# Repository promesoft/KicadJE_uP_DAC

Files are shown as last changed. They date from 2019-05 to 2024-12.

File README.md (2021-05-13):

# KicadJE_uP_DAC
Eurorack DAC output

# Purpose
Use for DDS/DCO - LFO - ADSR - Effects unit

# Status - Preliminary mounted
## Initial 
| Stage  | Detail | Status |
| --- | --- | --- |
| create material  | sch/pcb | OK  |
| | gerber | OK |
| production  | | ok |
|  | produced | ok |
|  | delivered | ok |
## Preliminary validation
| Test  | Detail | Status |
| --- | --- | --- |
| Initial Inspection | | OK |
| Initial Technical Test | ATMega32A DAC | ADC not working due to GND conn to Aref |
| Initial Technical Test | STM32 DAC |  |
| Initial Technical Test | VCO555 | Initial version not oscillating - add 270R across C603 to make it work |
|  |  | TL074 warm |
| Initial Product Test | ATMega32A DAC |  |
| Initial Product Test | STM32 DAC |  |
| Initial Product Test | VCO555 |  |
| Power Draw | ATMega32A DAC | Proto - no DAC: 2mA -12V, 2mA +12V, 30mA +5V |
| Power Draw | STM32 DAC |  |
| Power Draw | VCO555 |  |

## Secondary validation
| Test  | Detail | Status |
| --- | --- |--- |
| Product Test |  | |
| Product Test |  |  |
| Quality | | |
| Quality | | |
| Long Term Product Test |  |  |
| Power Draw | ATMega32A DAC |  |
| Power Draw | STM32 DAC |  |
| Power Draw | VCO555 |  |

## Errata
### Errata - VCO 555
1 - No oscillation fixed by replacing C603 w resistor (tested w 270R)
### Errata - ADSR Mega32
1 - ADC not working due to GND conn to Aref
### Errata - STM32 DAC

## Issues and Notes
### VCO 555

### ADSR Mega32
ADC not fast enough for audio

### STM32 DAC

# Pictures
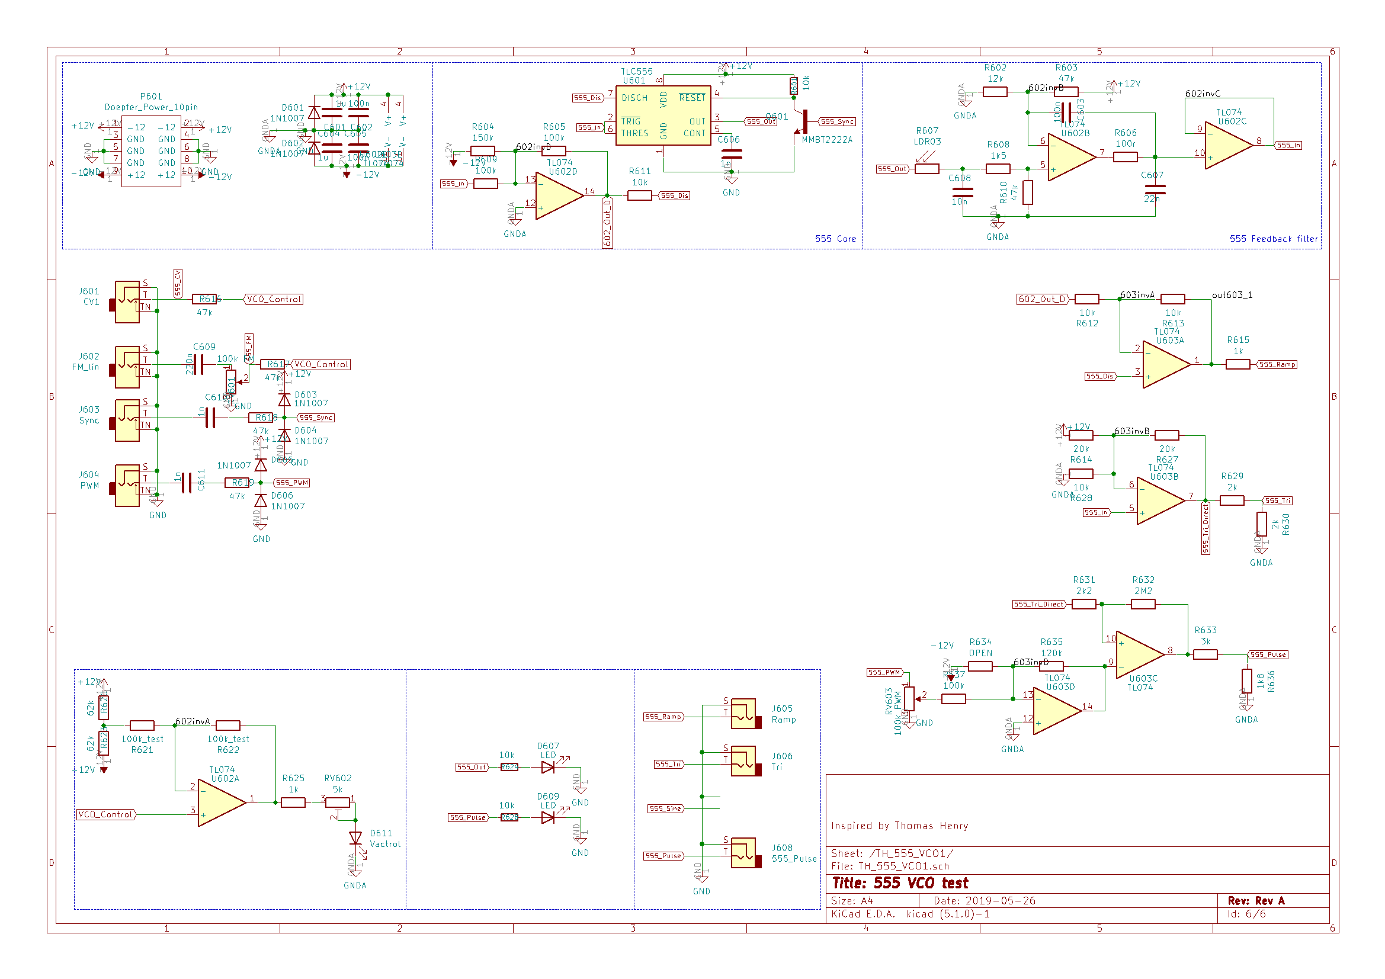
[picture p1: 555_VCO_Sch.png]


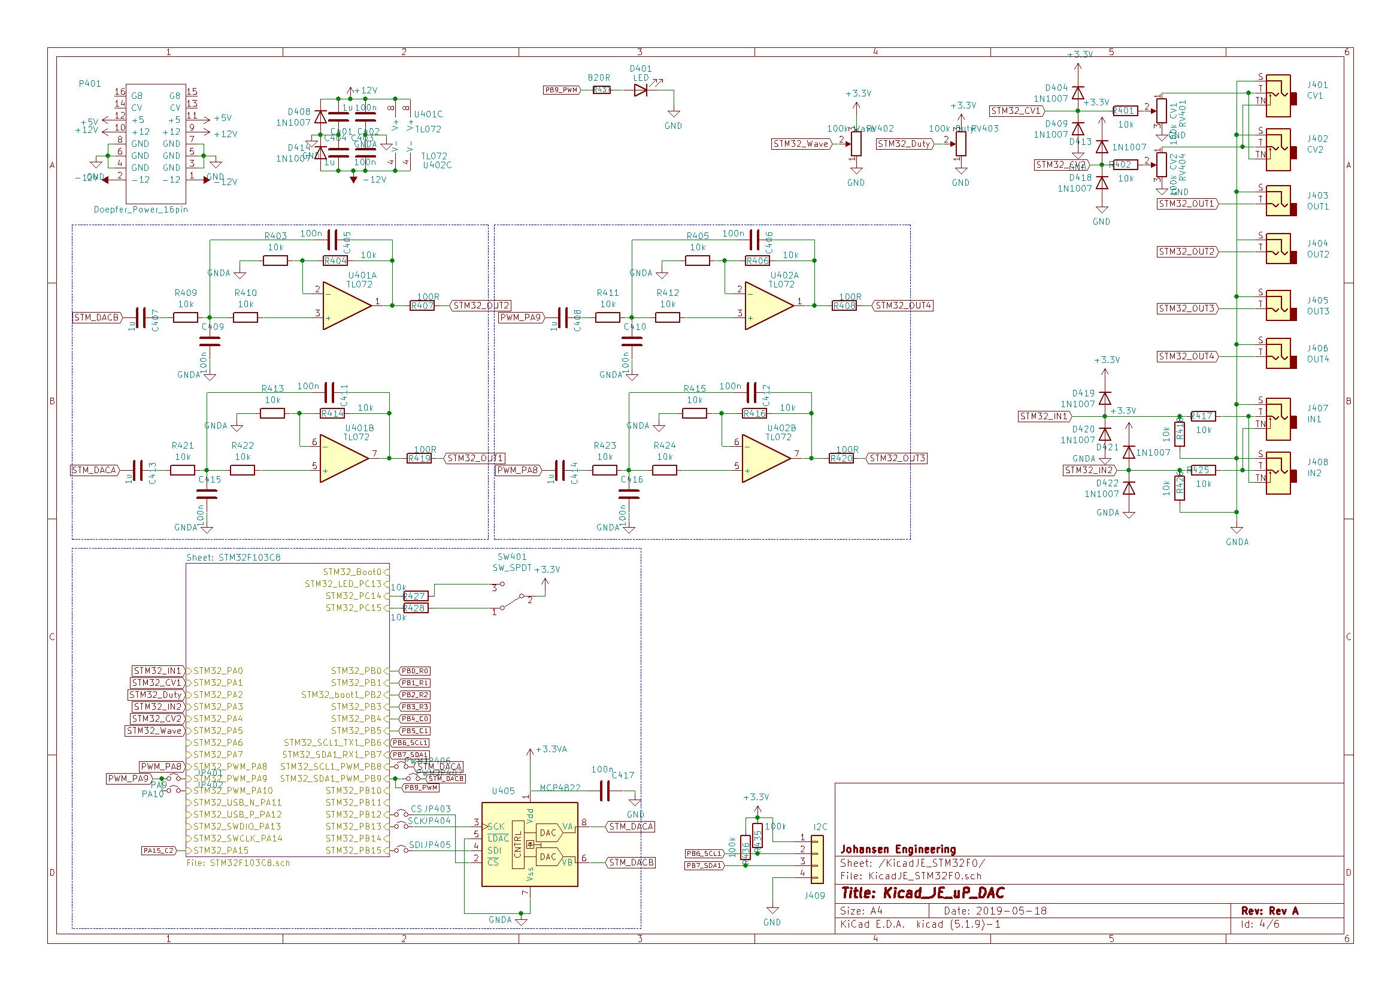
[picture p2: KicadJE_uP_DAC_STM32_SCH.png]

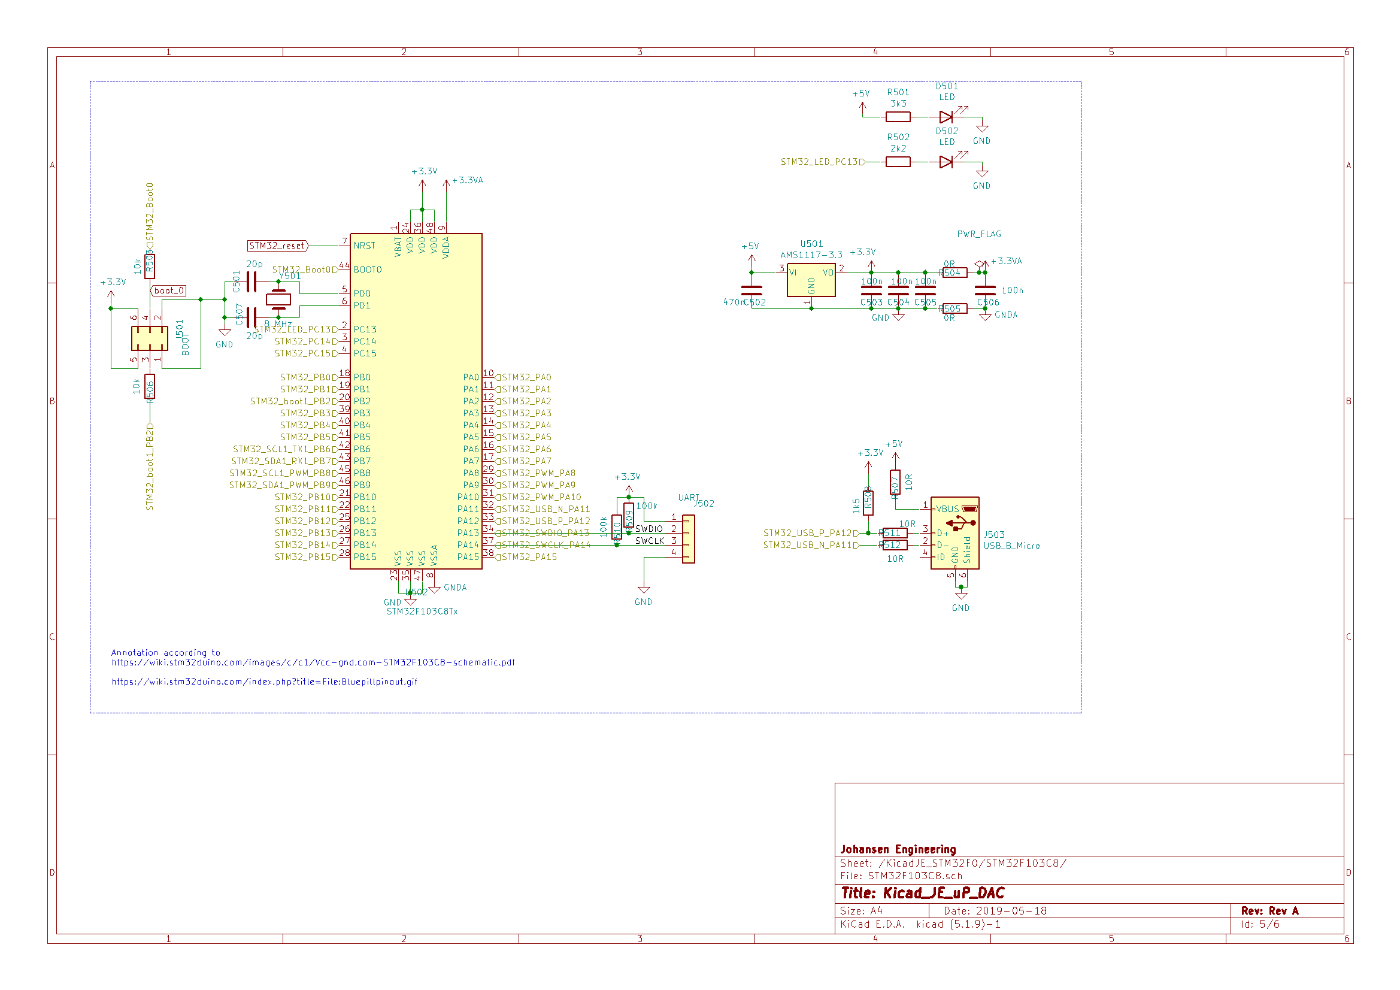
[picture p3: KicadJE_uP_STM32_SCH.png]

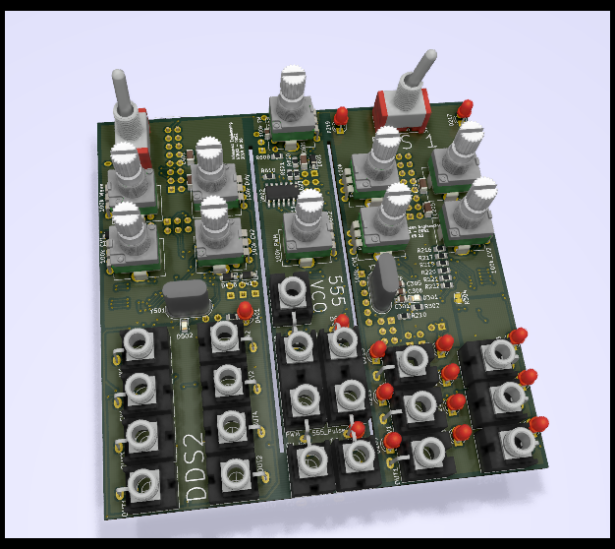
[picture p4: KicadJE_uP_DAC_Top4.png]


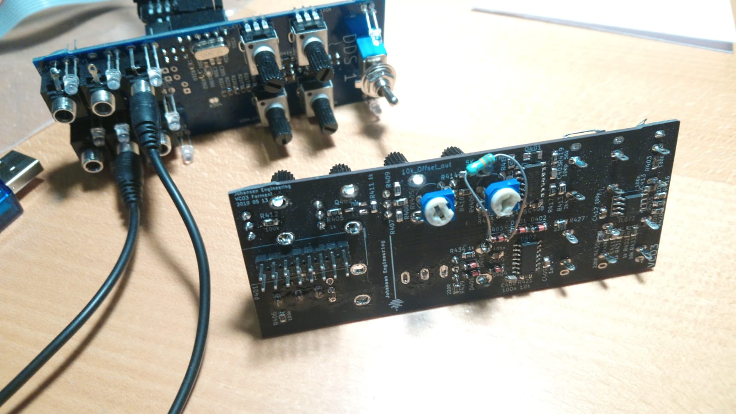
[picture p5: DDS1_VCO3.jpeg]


# Other components
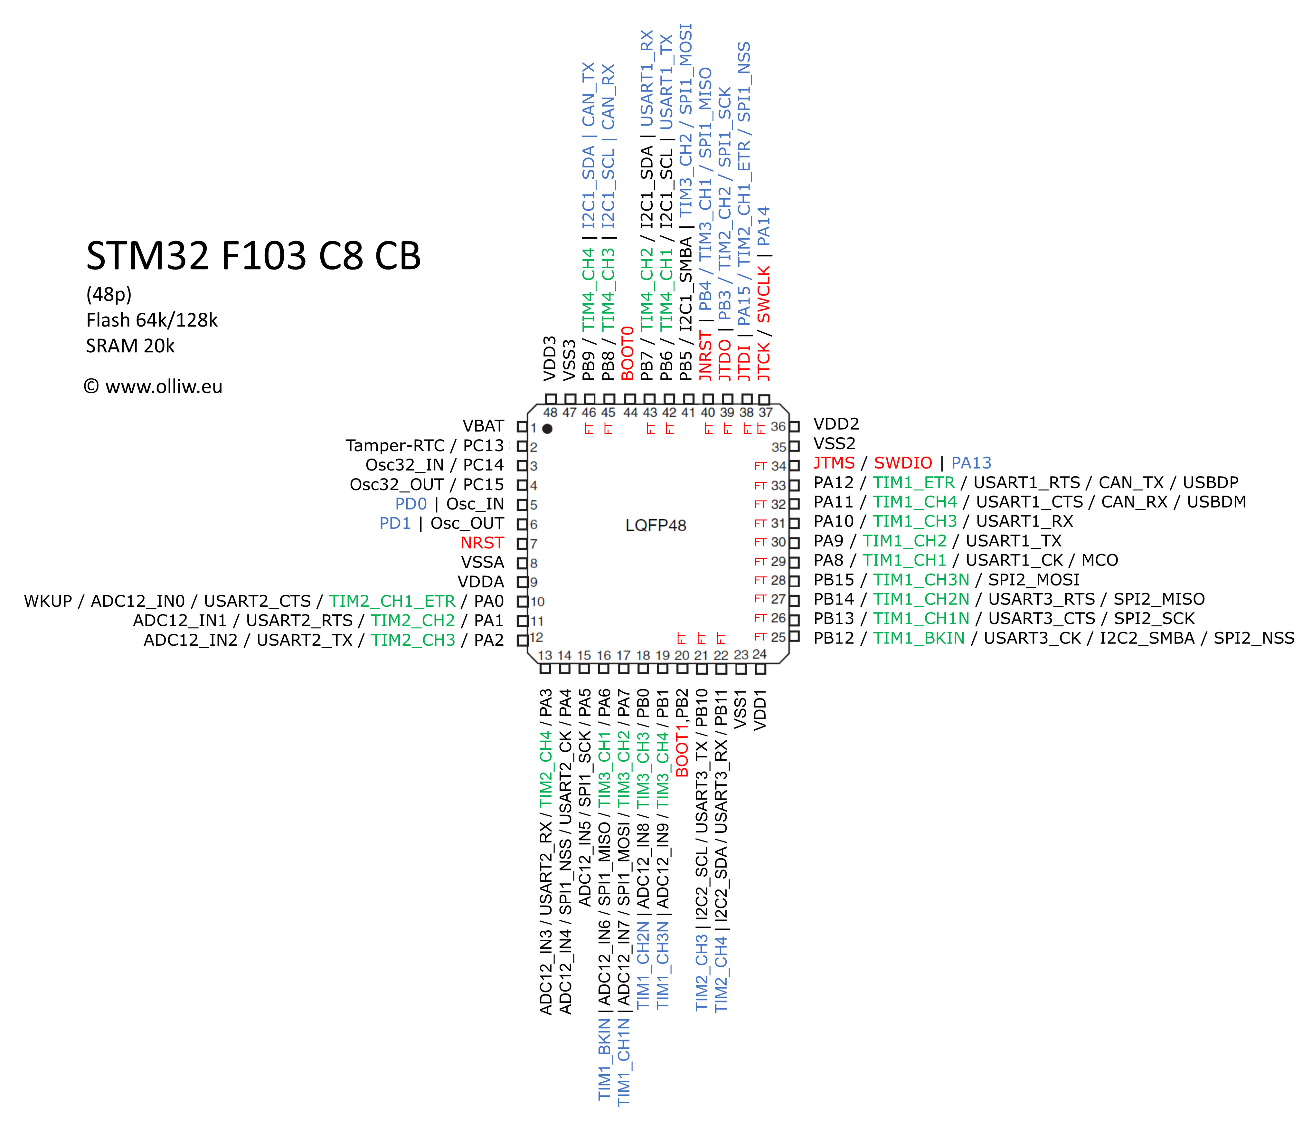
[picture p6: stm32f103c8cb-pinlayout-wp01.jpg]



# Inspiration
## ATMega 32A
https://github.com/MCUdude/MightyCore
## STM32

## Simple 555 VCO

### Own Projects
https://github.com/promesoft/KicadFormantVCO

https://github.com/promesoft/KicadJE_LFO_1

### Intro about 555
https://www.electronics-tutorials.ws/waveforms/555_oscillator.html

### Thomas Henry 555 VCO

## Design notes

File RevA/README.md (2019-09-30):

# KicadJE_uP_DAC
Eurorack DAC output

# Purpose
Use for DDS/DCO - LFO - ADSR - Effects unit

# Status - Preliminary SCH/PCB In the mail
## Initial 
| Stage  | Detail | Status |
| --- | --- | --- |
| create material  | sch/pcb | OK  |
| | gerber | OK |
| production  | | Ordered |
|  | produced | Pending |
|  | delivered | in the mail |
## Preliminary validation
| Test  | Detail | Status |
| --- | --- | --- |
| Initial Inspection | |  |
| Initial Technical Test | ATMega32A DAC |  |
| Initial Technical Test | STM32 DAC |  |
| Initial Technical Test | VCO555 |  |
| Initial Product Test | ATMega32A DAC |  |
| Initial Product Test | STM32 DAC |  |
| Initial Product Test | VCO555 |  |

## Secondary validation
| Test  | Detail | Status |
| --- | --- |--- |
| Product Test |  | |
| Product Test |  |  |
| Quality | | |
| Quality | | |
| Long Term Product Test |  |  |
| Power Draw |  | 

## Errata
### Errata -

## Issues and Notes
### 

# Pictures



# Other components



# Inspiration
## ATMega 32A
https://github.com/MCUdude/MightyCore
## STM32

## Simple 555 VCO

### Own Projects
https://github.com/promesoft/KicadFormantVCO

https://github.com/promesoft/KicadJE_LFO_1

### Intro about 555
https://www.electronics-tutorials.ws/waveforms/555_oscillator.html

### Thomas Henry 555 VCO
Nice comprehensive VCO

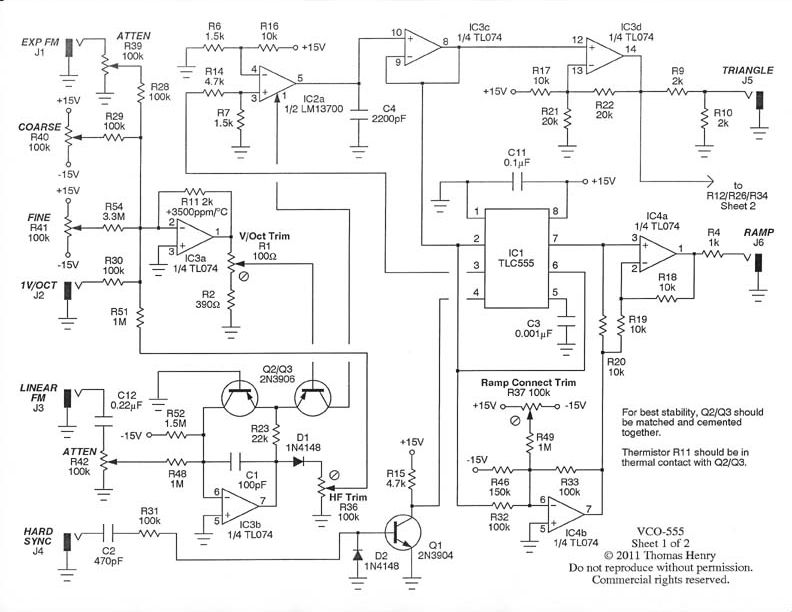
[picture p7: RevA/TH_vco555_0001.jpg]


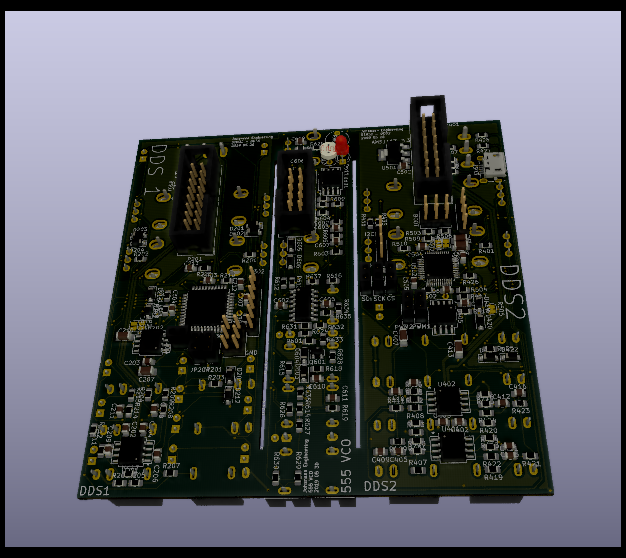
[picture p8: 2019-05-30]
RevA/KicadJE_uP_DAC_Bottom1.png

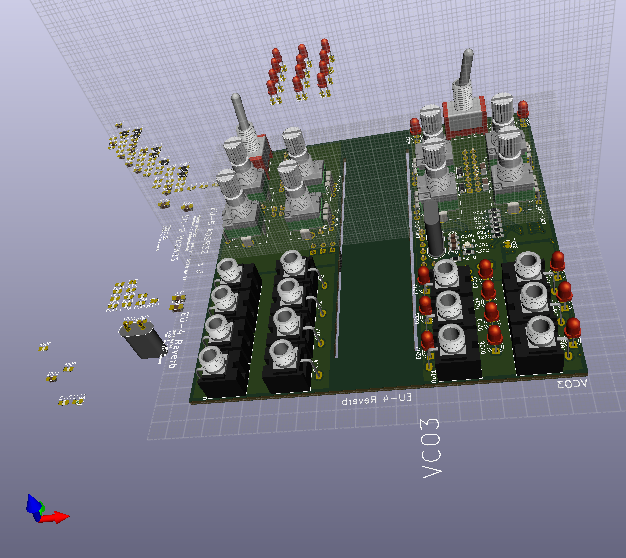
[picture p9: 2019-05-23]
RevA/KicadJE_uP_DAC_Top1.png

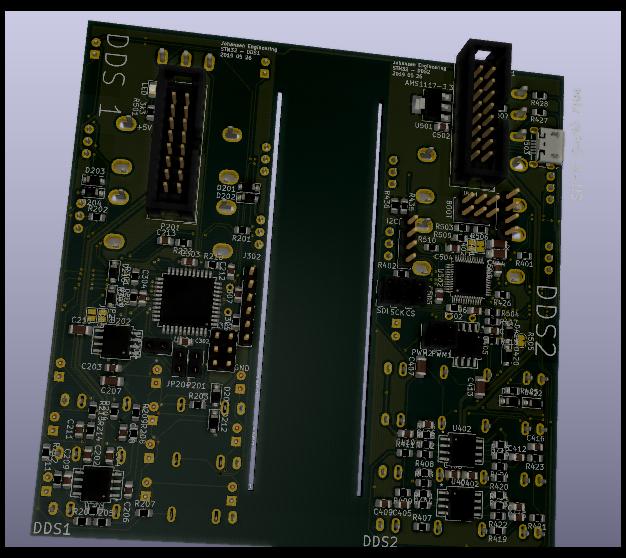
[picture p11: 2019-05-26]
RevA/KicadJE_uP_DAC_back2.jpg

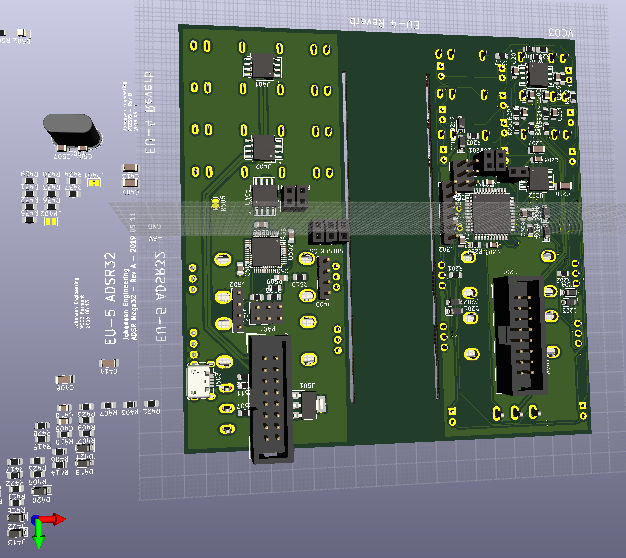
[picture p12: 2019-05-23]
RevA/KicadJE_uP_DAC.png

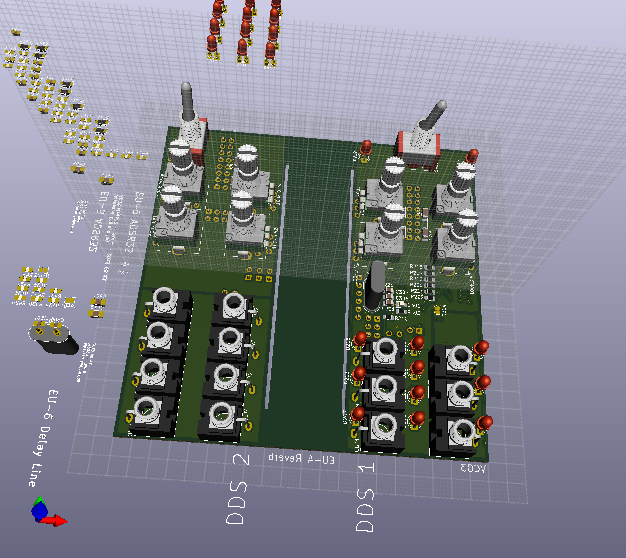
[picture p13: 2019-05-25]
RevA/KicadJE_uP_DAC_Top2.png

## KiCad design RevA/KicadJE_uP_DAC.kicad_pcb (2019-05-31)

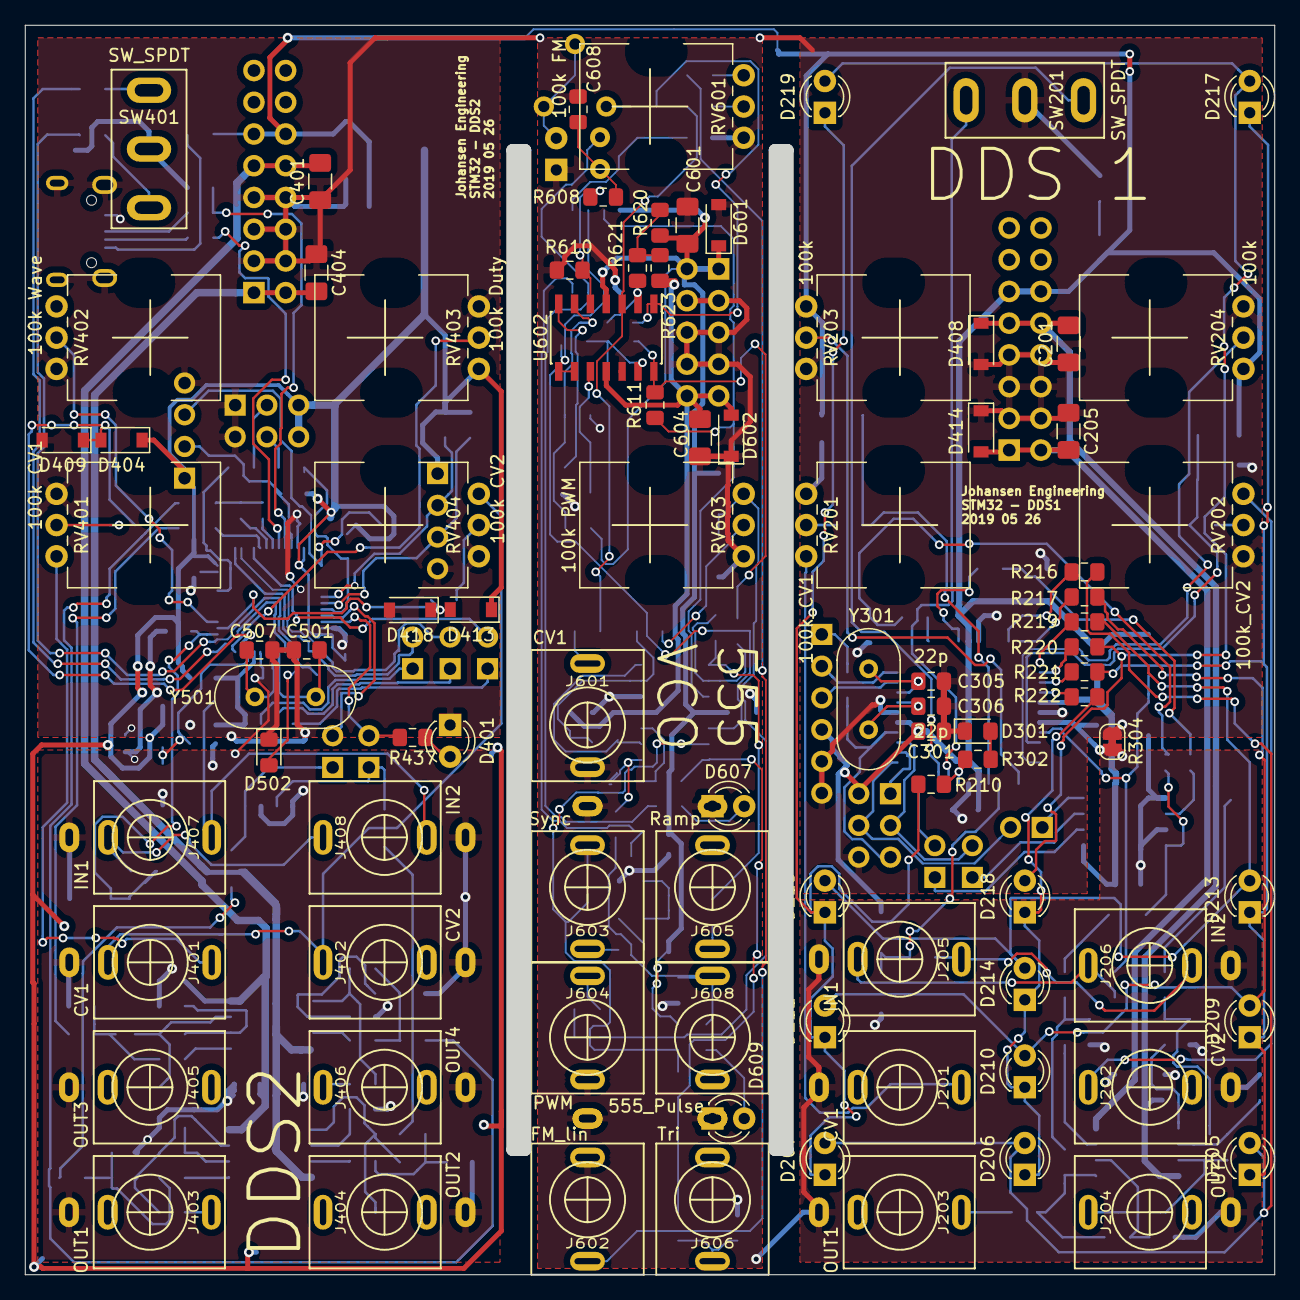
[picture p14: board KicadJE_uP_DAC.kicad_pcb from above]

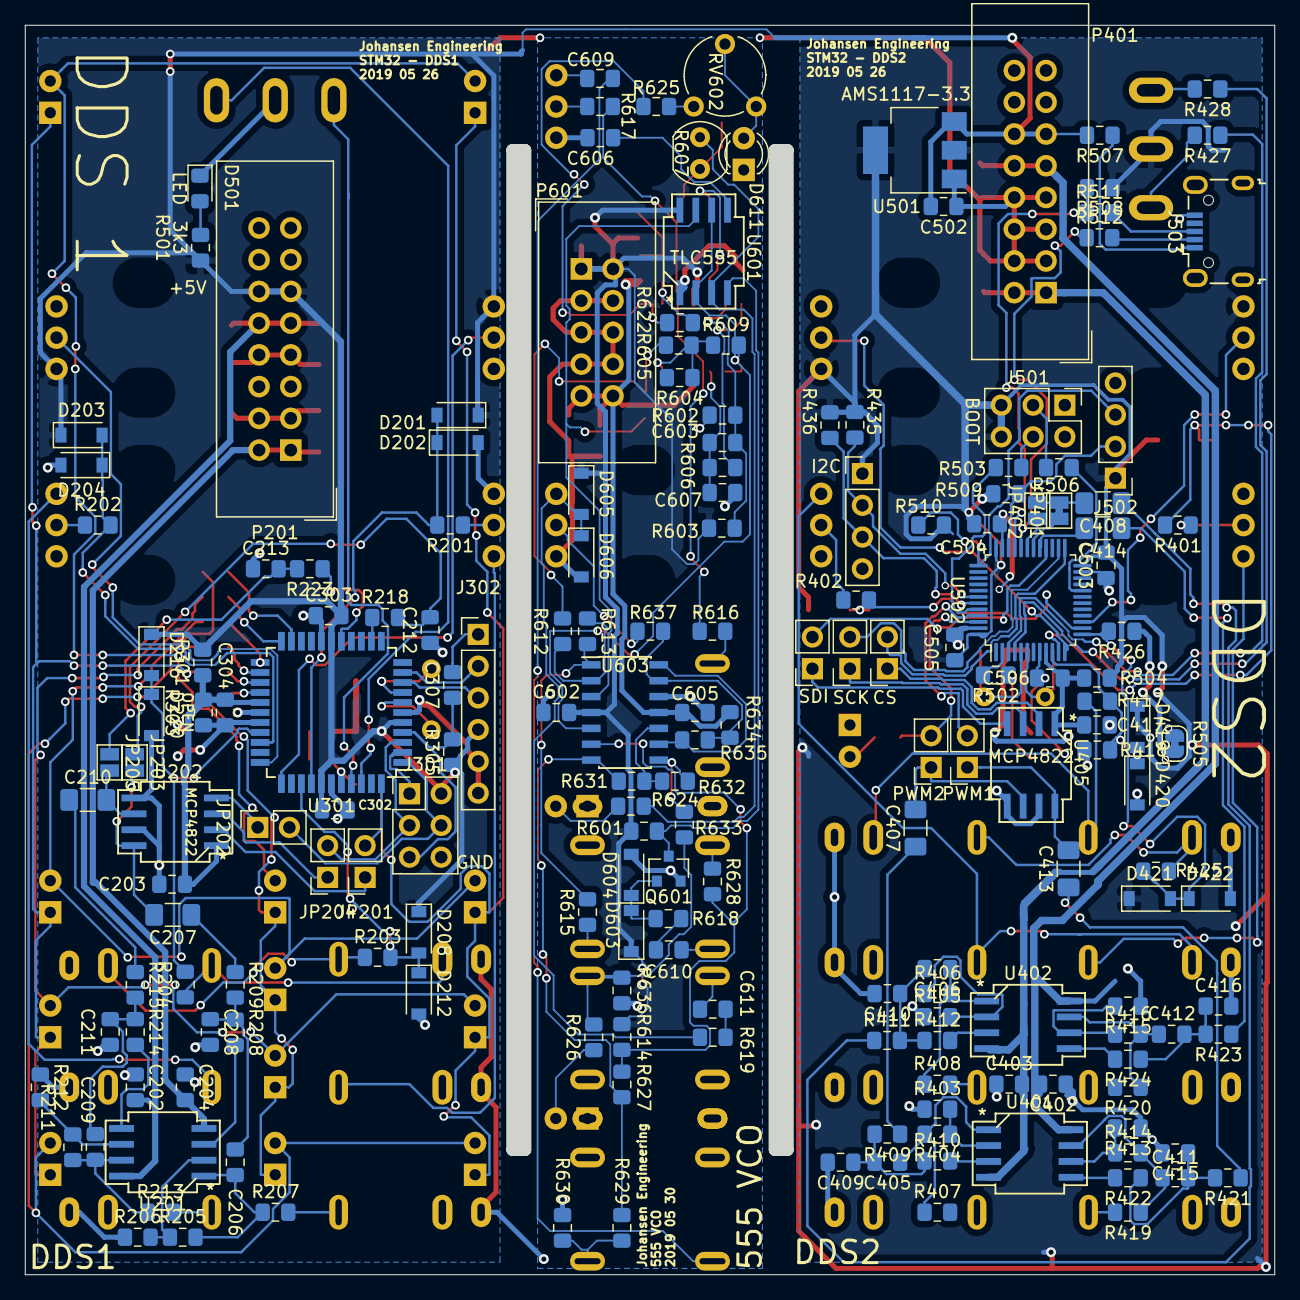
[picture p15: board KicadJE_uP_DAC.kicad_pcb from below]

Board: 2 copper layers, 100.0 x 100.0 mm, 275 parts (186 on the bottom side), 182 nets.

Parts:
C201, C205, C207, C210, C401, C404, C407, C408, C413, C414, C601, C604: 1u; C_1206_3216Metric_Pad1.42x1.75mm_HandSolder
C202, C203, C204, C206, C208, C209, C211, C212, C213, C301, C302, C303, C304, C307, C402, C403, C405, C406, C409, C410, C411, C412, C415, C416, C417, C503, C504, C505, C506, C602, C603, C605: 100n; C_0805_2012Metric_Pad1.15x1.40mm_HandSolder
C305, C306: 22p; C_0805_2012Metric_Pad1.15x1.40mm_HandSolder
C501, C507: 20p; C_0805_2012Metric_Pad1.15x1.40mm_HandSolder
C502: 470n; C_0805_2012Metric_Pad1.15x1.40mm_HandSolder
C606, C610, C611: 1n; C_0805_2012Metric_Pad1.15x1.40mm_HandSolder
C607: 22n; C_0805_2012Metric_Pad1.15x1.40mm_HandSolder
C608: 10n; C_0805_2012Metric_Pad1.15x1.40mm_HandSolder
C609: 220n; C_0805_2012Metric_Pad1.15x1.40mm_HandSolder
D201, D202, D203, D204, D208, D212, D216, D220, D404, D408, D409, D413, D414, D418, D419, D420, D421, D422, D601, D602, D603, D604, D605, D606: 1N1007; D_SOD-123
D205, D206, D207, D209, D210, D211, D213, D214, D215, D217, D218, D219, D401, D607, D609: LED; LED_D3.0mm
D301, D501, D502: LED; LED_0805_2012Metric_Pad1.15x1.40mm_HandSolder
D611: Vactrol; LED_D3.0mm
J201, J401, J601: CV1; PJ301SM
J202, J402: CV2; PJ301SM
J203, J403: OUT1; PJ301SM
J204, J404: OUT2; PJ301SM
J205, J407: IN1; PJ301SM
J206, J408: IN2; PJ301SM
J301: AVR-ISP-6; PinHeader_2x03_P2.54mm_Vertical
J302: UART; PinHeader_1x06_P2.54mm_Vertical
J405: OUT3; PJ301SM
J406: OUT4; PJ301SM
J409: I2C; PinHeader_1x04_P2.54mm_Vertical
J501: BOOT; PinHeader_2x03_P2.54mm_Vertical
J502: UART; PinHeader_1x04_P2.54mm_Vertical
J503: USB_B_Micro; USB_Micro-B_Wuerth_629105150521
J602: FM_lin; PJ301SM
J603: Sync; PJ301SM
J604: PWM; PJ301SM
J605: Ramp; PJ301SM
J606: Tri; PJ301SM
J608: 555_Pulse; PJ301SM
JP201: SS; PinSocket_1x02_P2.54mm_Vertical
JP202: MOSI; PinSocket_1x02_P2.54mm_Vertical
JP203: PWM1; SolderJumper-2_P1.3mm_Open_Pad1.0x1.5mm
JP204, JP404: SCK; PinSocket_1x02_P2.54mm_Vertical
JP205: PWM2; SolderJumper-2_P1.3mm_Open_Pad1.0x1.5mm
JP401: PA9; SolderJumper-2_P1.3mm_Bridged_Pad1.0x1.5mm
JP402: PA10; SolderJumper-2_P1.3mm_Open_Pad1.0x1.5mm
JP403: CS; PinSocket_1x02_P2.54mm_Vertical
JP405: SDI; PinSocket_1x02_P2.54mm_Vertical
JP406: PWM1; PinSocket_1x02_P2.54mm_Vertical
JP407: PWM2; PinSocket_1x02_P2.54mm_Vertical
P201, P401: Doepfer_Power_16pin; IDC-Header_2x08_Pitch2.54mm_Straight
P601: Doepfer_Power_10pin; IDC-Header_2x05_Pitch2.54mm_Straight
Q601: MMBT2222A; SOT-23
R201, R202, R203, R204, R205, R206, R208, R209, R211, R212, R214, R215, R305, R401, R402, R403, R404, R405, R406, R409, R410, R411, R412, R413, R414, R415, R416, R417, R418, R421, R422, R423, R424, R425, R426, R427, R428, R503, R506, R601, R611, R612, R613, R624, R626, R628: 10k; R_0805_2012Metric_Pad1.15x1.40mm_HandSolder
R207, R210, R213, R216, R217, R219, R220, R221, R222, R407, R408, R419, R420: 100R; R_0805_2012Metric_Pad1.15x1.40mm_HandSolder
R218, R223, R302, R615, R625: 1k; R_0805_2012Metric_Pad1.15x1.40mm_HandSolder
R301, R504: 0R; R_0805_2012Metric_Pad1.15x1.40mm_HandSolder
R303, R634: OPEN; R_0805_2012Metric_Pad1.15x1.40mm_HandSolder
R304, R505: 0R; SolderJumper-2_P1.3mm_Bridged_RoundedPad1.0x1.5mm
R435, R436, R509, R510, R605, R609, R637: 100k; R_0805_2012Metric_Pad1.15x1.40mm_HandSolder
R437: 820R; R_0805_2012Metric_Pad1.15x1.40mm_HandSolder
R501: 3k3; R_0805_2012Metric_Pad1.15x1.40mm_HandSolder
R502, R631: 2k2; R_0805_2012Metric_Pad1.15x1.40mm_HandSolder
R507, R511, R512: 10R; R_0805_2012Metric_Pad1.15x1.40mm_HandSolder
R508, R608: 1k5; R_0805_2012Metric_Pad1.15x1.40mm_HandSolder
R602: 12k; R_0805_2012Metric_Pad1.15x1.40mm_HandSolder
R603, R610, R616, R617, R618, R619: 47k; R_0805_2012Metric_Pad1.15x1.40mm_HandSolder
R604: 150k; R_0805_2012Metric_Pad1.15x1.40mm_HandSolder
R606: 100r; R_0805_2012Metric_Pad1.15x1.40mm_HandSolder
R607: LDR03; R_LDR_4.9x4.2mm_P2.54mm_Vertical
R614, R627: 20k; R_0805_2012Metric_Pad1.15x1.40mm_HandSolder
R620, R623: 62k; R_0805_2012Metric_Pad1.15x1.40mm_HandSolder
R621, R622: 100k_test; R_0805_2012Metric_Pad1.15x1.40mm_HandSolder
R629, R630: 2k; R_0805_2012Metric_Pad1.15x1.40mm_HandSolder
R632: 2M2; R_0805_2012Metric_Pad1.15x1.40mm_HandSolder
R633: 3k; R_0805_2012Metric_Pad1.15x1.40mm_HandSolder
R635: 120k; R_0805_2012Metric_Pad1.15x1.40mm_HandSolder
R636: 1k8; R_0805_2012Metric_Pad1.15x1.40mm_HandSolder
RV201: 100k_CV1; Potentiometer_China_RK09_Single_Vertical_AJ
RV202: 100k_CV2; Potentiometer_China_RK09_Single_Vertical_AJ
RV203, RV204: 100k; Potentiometer_China_RK09_Single_Vertical_AJ
RV401: 100k CV1; Potentiometer_China_RK09_Single_Vertical_AJ
RV402: 100k Wave; Potentiometer_China_RK09_Single_Vertical_AJ
RV403: 100k Duty; Potentiometer_China_RK09_Single_Vertical_AJ
RV404: 100k CV2; Potentiometer_China_RK09_Single_Vertical_AJ
RV601: 100k FM; Potentiometer_China_RK09_Single_Vertical_AJ
RV602: 5k; Potentiometer_Piher_PT-6-V_Vertical
RV603: 100k PWM; Potentiometer_China_RK09_Single_Vertical_AJ
SW201, SW401: SW_SPDT; SP1MS1
U201, U401, U402: TL072; AJ_SO-8_5.3x6.2mm_P1.27mm
U202, U405: MCP4822; AJ_SO-8_5.3x6.2mm_P1.27mm
U301: ATmega32A-AU; TQFP-44_10x10mm_P0.8mm
U501: AMS1117-3.3; SOT-223-3_TabPin2
U502: STM32F103C8Tx; LQFP-48_7x7mm_P0.5mm
U601: TLC555; AJ_SO-8_5.3x6.2mm_P1.27mm
U602, U603: TL074; SOIC-14_3.9x8.7mm_P1.27mm
Y301: 16MHz; Crystal_HC49-U_Vertical
Y501: 8 MHz; Crystal_HC49-U_Vertical

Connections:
32_0_LED: R210.1, R302.2, U301.40
32_1: SW201.3, U301.41
32_2_INT2: SW201.1, U301.42
32_4_SS_PWM: JP201.2, U301.44
32_5_MOSI: J301.4, JP202.2, U301.1
32_6_MISO: J301.1, U301.2
32_7_SCK: J301.3, JP204.2, U301.3
32_8_Rx: J302.3, U301.9
32_9_Tx: J302.2, U301.10
32_12_PWM: R218.1, U301.13
32_15_PWM: R223.1, U301.16
32_reset: C307.1, J301.5, R305.2, U301.4
555_CV: J601.T, R616.1
555_Dis: R611.1, U601.7, U603.3
555_FM: R617.1, RV601.2
555_In: R609.2, U601.2, U601.6, U602.8, U602.9, U603.5
555_Out: R607.2, R624.2, U601.3
555_PWM: D605.2, D606.1, R619.2, RV603.1
555_Pulse: J608.T, R626.2, R633.1, R636.2
555_Ramp: J605.T, R615.1
555_Sync: D603.2, D604.1, Q601.1, R618.2
555_Tri: J606.T, R629.1, R630.2
555_Tri_Direct: R627.2, R629.2, R631.2, U603.7
602_Out_D: R605.1, R611.2, R612.1, U602.14
+3.3VA: C417.1, C506.2, R504.1, U405.1, U502.9
+3V3: C503.2, C504.2, C505.2, D404.1, D413.1, D419.1, D421.1, J409.1, J501.5, J501.6, J502.1, R435.2, R436.2, R504.2, R508.1, R509.2, R510.2, RV402.3, RV403.3, SW401.2, U501.2, U502.24, U502.36, U502.48
+5V: C301.2, C302.2, C303.2, C502.2, D201.1, D203.1, D208.1, D216.1, J301.2, J302.4, P201.11, P201.12, P401.11, P401.12, R301.2, R305.1, R501.2, R507.2, RV203.3, RV204.3, U301.5, U301.17, U301.38, U501.3
+5VA: C203.2, C304.2, R301.1, R303.1, U202.1, U301.27
+12V: C201.2, C202.2, C401.2, C402.2, C601.2, C602.2, D408.1, D601.1, D603.1, D605.1, P201.9, P201.10, P401.9, P401.10, P601.1, P601.2, R601.2, R603.1, R614.1, R620.2, U201.8, U401.8, U402.8, U601.8, U602.4, U603.4
-12V: C204.2, C205.2, C403.2, C404.2, C604.2, C605.2, D414.2, D602.2, P201.1, P201.2, P401.1, P401.2, P601.9, P601.10, R604.2, R623.1, R634.2, U201.4, U401.4, U402.4, U602.11, U603.11
/KicadJE_ATMega32A_DAC/1_inv: R205.1, R206.2, U201.2
/KicadJE_ATMega32A_DAC/1_noninv: R208.2, U201.3
/KicadJE_ATMega32A_DAC/1_out: C206.1, R205.2, R207.1, U201.1
/KicadJE_ATMega32A_DAC/2_inv: R211.1, R212.2, U201.6
/KicadJE_ATMega32A_DAC/2_noninv: R214.2, U201.5
/KicadJE_ATMega32A_DAC/2_out: C209.1, R211.2, R213.1, U201.7
/KicadJE_ATMega32A_DAC/ATMega32A.sch/18: R216.1, U301.21
/KicadJE_ATMega32A_DAC/ATMega32A.sch/19: R217.1, U301.22
/KicadJE_ATMega32A_DAC/ATMega32A.sch/20: R219.1, U301.23
/KicadJE_ATMega32A_DAC/ATMega32A.sch/21: R220.1, U301.24
/KicadJE_ATMega32A_DAC/ATMega32A.sch/22: R221.1, U301.25
/KicadJE_ATMega32A_DAC/ATMega32A.sch/23: R222.1, U301.26
/KicadJE_ATMega32A_DAC/SCK: JP204.1, U202.3
/KicadJE_ATMega32A_DAC/SDI: JP202.1, U202.4
/KicadJE_ATMega32A_DAC/SS: JP201.1, U202.2
/KicadJE_STM32F0/STM32F103C8/STM32_Boot0: R503.2, U502.44
/KicadJE_STM32F0/STM32F103C8/STM32_LED_PC13: R502.2, U502.2
/KicadJE_STM32F0/STM32F103C8/STM32_PB12: JP403.2, U502.25
/KicadJE_STM32F0/STM32F103C8/STM32_PB13: JP404.2, U502.26
/KicadJE_STM32F0/STM32F103C8/STM32_PB15: JP405.2, U502.28
/KicadJE_STM32F0/STM32F103C8/STM32_PC14: R427.1, U502.3
/KicadJE_STM32F0/STM32F103C8/STM32_PC15: R428.1, U502.4
/KicadJE_STM32F0/STM32F103C8/STM32_PWM_PA9: JP401.1, U502.30
/KicadJE_STM32F0/STM32F103C8/STM32_PWM_PA10: JP402.1, U502.31
/KicadJE_STM32F0/STM32F103C8/STM32_SCL1_PWM_PB8: JP406.2, U502.45
/KicadJE_STM32F0/STM32F103C8/STM32_SWCLK_PA14: J502.3, R510.1, U502.37
/KicadJE_STM32F0/STM32F103C8/STM32_SWDIO_PA13: J502.2, R509.1, U502.34
/KicadJE_STM32F0/STM32F103C8/STM32_USB_N_PA11: R512.1, U502.32
/KicadJE_STM32F0/STM32F103C8/STM32_USB_P_PA12: R508.2, R511.1, U502.33
/TH_555_VCO1/602invA: R621.2, R622.1, U602.2
/TH_555_VCO1/602invB: C603.2, R602.1, R603.2, U602.6
/TH_555_VCO1/602invD: R604.1, R605.2, R609.1, U602.13
/TH_555_VCO1/603invA: R612.2, R613.1, U603.2
/TH_555_VCO1/603invB: R614.2, R627.1, R628.2, U603.6
/TH_555_VCO1/603invD: R634.1, R635.2, R637.1, U603.13
/TH_555_VCO1/out603_1: R613.2, R615.2, U603.1
C0_22: D205.1, D209.1, D213.1, D217.1, R221.2
C1_23: D206.1, D210.1, D214.1, D218.1, R222.2
C2_0: D207.1, D211.1, D215.1, D219.1, R210.2
CV1: D201.2, D202.1, R201.2, U301.37
CV2: D203.2, D204.1, R202.2, U301.31
DACA: C207.2, JP203.2, U202.8
DACB: C210.2, JP205.2, U202.6
Duty: RV204.2, U301.33
GND: C201.1, C202.1, C203.1, C204.1, C205.1, C208.2, C211.2, C212.1, C213.1, C301.1, C302.1, C303.1, C304.1, C305.2, C306.2, C401.1, C402.1, C403.1, C404.1, C409.2, C410.2, C415.2, C416.2, C417.2, C501.2, C502.1, C503.1, C504.1, C505.1, C506.1, C507.2, C601.1, C602.1, C604.1, C605.1, C606.2, C607.2, C608.2, D202.2, D204.2, D212.2, D220.2, D301.1, D401.1, D408.2, D409.2, D414.1, D418.2, D420.2, D422.2, D501.1, D502.1, D601.2, D602.1, D604.2, D606.2, D607.1, D609.1, D611.1, J201.S, J202.S, J203.S, J204.S, J205.S, J206.S, J301.6, J302.5, J302.6, J401.S, J402.S, J403.S, J404.S, J405.S, J406.S, J407.S, J408.S, J409.4, J501.1, J501.2, J502.4, J503.5, J503.6, J601.S, J601.TN, J602.S, J602.TN, J603.S, J603.TN, J604.S, J604.TN, J605.S, J606.S, J608.S, P201.3, P201.4, P201.5, P201.6, P201.7, P201.8, P401.3, P401.4, P401.5, P401.6, P401.7, P401.8, P601.3, P601.4, P601.5, P601.6, P601.7, P601.8, Q601.2, R206.1, R212.1, R303.2, R304.1, R304.2, R403.1, R405.1, R413.1, R415.1, R418.1, R426.1, R505.1, R505.2, R602.2, R610.2, R628.1, R630.1, R636.1, RV201.3, RV202.3, RV203.1, RV204.1, RV401.3, RV402.1, RV403.1, RV404.3, RV601.3, RV603.3, SW201.2, U202.5, U202.7, U301.6, U301.18, U301.28, U301.29, U301.39, U405.5, U405.7, U501.1, U502.8, U502.23, U502.35, U502.47, U601.1, U602.12, U603.12
IN1: D208.2, D212.1, R203.2, U301.36
IN2: D216.2, D220.1, R204.2, U301.30
unnamed: C206.2, C208.1, R208.1, R209.2
unnamed: C207.1, R209.1
unnamed: C209.2, C211.1, R214.1, R215.2
unnamed: C210.1, R215.1
unnamed: C305.1, U301.8, Y301.1
unnamed: C306.1, U301.7, Y301.2
unnamed: C307.2, J302.1
unnamed: C405.1, R404.2, R407.1, U401.1
unnamed: C405.2, C409.1, R409.2, R410.1
unnamed: C406.1, R406.2, R408.1, U402.1
unnamed: C406.2, C410.1, R411.2, R412.1
unnamed: C407.1, R409.1
unnamed: C408.1, R411.1
unnamed: C411.1, R414.2, R419.1, U401.7
unnamed: C411.2, C415.1, R421.2, R422.1
unnamed: C412.1, R416.2, R420.1, U402.7
unnamed: C412.2, C416.1, R423.2, R424.1
unnamed: C413.1, R421.1
unnamed: C414.1, R423.1
unnamed: C501.1, U502.5, Y501.1
unnamed: C507.1, U502.6, Y501.2
unnamed: C603.1, C607.1, R606.1, U602.10
unnamed: C606.1, U601.5
unnamed: C608.1, R607.1, R608.2
unnamed: C609.1, RV601.1
unnamed: C609.2, J602.T
unnamed: C610.1, R618.1
unnamed: C610.2, J603.T
unnamed: C611.1, R619.1
unnamed: C611.2, J604.T
unnamed: D301.2, R302.1
unnamed: D401.2, R437.1
unnamed: D501.2, R501.1
unnamed: D502.2, R502.1
unnamed: D607.2, R624.1
unnamed: D609.2, R626.1
unnamed: D611.2, RV602.1, RV602.2
unnamed: J201.T, J202.TN, RV201.1
unnamed: J201.TN, J202.T, RV202.1
unnamed: J205.T, J206.TN, R203.1
unnamed: J205.TN, J206.T, R204.1
unnamed: J401.T, J402.TN, RV401.1
unnamed: J401.TN, J402.T, RV404.1
unnamed: J407.T, J408.TN, R417.1
unnamed: J407.TN, J408.T, R425.1
unnamed: J501.3, R506.1
unnamed: J503.1, R507.1
unnamed: J503.2, R512.2
unnamed: J503.3, R511.2
unnamed: JP403.1, U405.2
unnamed: JP404.1, U405.3
unnamed: JP405.1, U405.4
unnamed: Q601.3, R601.1, U601.4
unnamed: R201.1, RV201.2
unnamed: R202.1, RV202.2
unnamed: R401.1, RV401.2
unnamed: R402.1, RV404.2
unnamed: R403.2, R404.1, U401.2
unnamed: R405.2, R406.1, U402.2
unnamed: R410.2, U401.3
unnamed: R412.2, U402.3
unnamed: R413.2, R414.1, U401.6
unnamed: R415.2, R416.1, U402.6
unnamed: R422.2, U401.5
unnamed: R424.2, U402.5
unnamed: R427.2, SW401.3
unnamed: R428.2, SW401.1
unnamed: R606.2, U602.7
unnamed: R608.1, R610.1, U602.5
unnamed: R620.1, R621.1, R623.2
unnamed: R622.2, R625.2, U602.1
unnamed: R625.1, RV602.3
unnamed: R631.1, R632.2, U603.10
unnamed: R632.1, R633.2, U603.8
unnamed: R635.1, U603.9, U603.14
unnamed: R637.2, RV603.2
OUT1: J203.T, R207.2
OUT2: J204.T, R213.2
PB2_R2: R506.2, U502.20
PB6_SCL1: J409.2, R435.1, U502.42
PB7_SDA1: J409.3, R436.1, U502.43
PB9_PWM: JP407.2, R437.2, U502.46
PWM12: C212.2, JP203.1, R218.2
PWM15: C213.2, JP205.1, R223.2
PWM_PA8: C414.2, U502.29
PWM_PA9: C408.2, JP401.2, JP402.2
R0_18: D205.2, D206.2, D207.2, R216.2
R1_19: D209.2, D210.2, D211.2, R217.2
R2_20: D213.2, D214.2, D215.2, R219.2
R3_21: D217.2, D218.2, D219.2, R220.2
STM32_CV1: D404.2, D409.1, R401.2, U502.11
STM32_CV2: D413.2, D418.1, R402.2, U502.14
STM32_Duty: RV403.2, U502.12
STM32_IN1: D419.2, D420.1, R417.2, R418.2, U502.10
STM32_IN2: D421.2, D422.1, R425.2, R426.2, U502.13
STM32_OUT1: J403.T, R419.2
STM32_OUT2: J404.T, R407.2
STM32_OUT3: J405.T, R420.2
STM32_OUT4: J406.T, R408.2
STM32_Wave: RV402.2, U502.15
STM_DACA: C413.2, JP406.1, U405.8
STM_DACB: C407.2, JP407.1, U405.6
VCO_Control: R616.2, R617.2, U602.3
Wave: RV203.2, U301.34
boot_0: J501.4, R503.1

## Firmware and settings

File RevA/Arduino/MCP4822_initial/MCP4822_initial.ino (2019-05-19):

/*
 * Origin:
 * http://www.kerrywong.com/2012/07/25/code-for-mcp4821-mcp4822/
 */

#include <SPI.h>
 
const int PIN_CS = 10;
const int GAIN_1 = 0x1;
const int GAIN_2 = 0x0;
 
void setup()
{
  pinMode(PIN_CS, OUTPUT);
  SPI.begin();  
  SPI.setClockDivider(SPI_CLOCK_DIV2);
}
 
//assuming single channel, gain=2
void setOutput(unsigned int val)
{
  byte lowByte = val & 0xff;
  byte highByte = ((val >> 8) & 0xff) | 0x10;
   
  PORTB &= 0xfb;
  SPI.transfer(highByte);
  SPI.transfer(lowByte);
  PORTB |= 0x4;
}
 
void setOutput(byte channel, byte gain, byte shutdown, unsigned int val)
{
  byte lowByte = val & 0xff;
  byte highByte = ((val >> 8) & 0xff) | channel << 7 | gain << 5 | shutdown << 4;
   
  PORTB &= 0xfb;
  SPI.transfer(highByte);
  SPI.transfer(lowByte);
  PORTB |= 0x4;
}
 
void loop()
{
 //high-res triangular wave
 for (int i=0; i < 4096; i+=32)   
 {
  //setOutput(0, GAIN_2, 1, i);
  setOutput(i);
 }
}

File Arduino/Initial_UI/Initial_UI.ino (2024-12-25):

/************************************************
https://mcudude.github.io/MightyCore/package_MCUdude_MightyCore_index.json
https://github.com/promesoft/KicadJE_uP_DAC
Program via USBasp

Purpose of the Board: CV controlled DDS generator
Operation of controls:
Top selector sw: left - center - right
Top LEDs: led - right (based on selector)
Top POT: left - selects bank
Top POT: right - selects waveform
// Center shows selected waveform (1,2,3,4)

// Top LED - Bank 1 (sine, half sine, sine^2, Sharkfin)
// Center LED - Bank 2 (Saw, inv Saw, tri, saw+inv saw)
// Bottom LED - Bank 3 (Square 10%, 25%, 10%..40%, noise)


Bottom POT: left - select CV sensitivity (analogue)
Bottom POT: right - select CV sensitivity (analogue)

top jack L/R: Input
middle jack L/R: CV
bottom jack L/R: Out

To do: only change the output if the pot has been changed
Introduce L/R states that can be changed if the pot val has changed
************************************************/

//LEDs
#define row0 18
#define row1 19
#define row2 20
#define row3 21
#define col0 0
#define col1 22
#define col2 23

//Switch
#define rightsel 1 //Digital pin for right select
#define leftsel 2 //Digital pin for left select

//POTs
#define topleft A3  // Wave = A3 = 27 = PA3
#define topright A4 // Duty = A4 = 28 = PA4

//CV
#define leftcv A0  // left = A0 = 24 = PA0 - J201 CV1 - left in
#define rightcv A6 // right = A6 = 30 = PA6 - J202 CV2 - right in
int right_cv, left_cv = 0;

//Output
#define leftout 12  // left = 12 - J203 OUT1 - PWM12/DACA - left out
#define rightout 15 // right = 15 - J204 OUT2 - PWM15/DACB - right out

//Input
#define leftin A1  // left = A1 = 25 = PA1 - J205 IN1 - left in
#define rightin A7 // right = A7 = 31 = PA7 - J206 IN2 - right in
int right_in, left_in = 0;

int sw_state = 0; // What should the pot's do? 0 = Left 1 = Right 2 = Center 
// Right/Left
// Top - show which side is selected
// Input - Bank 1 (sine, half sine, sine^2, Sharkfin)
// CV - Bank 2 (Saw, inv Saw, tri, saw+inv saw)
// Output - Bank 3 (Square 10%, 25%, 10%..40%, noise)
// Center shows selected waveform (1,2,3,4)
// Pot left selects bank
// Pot right selects waveform

// Center 
// L/R Input - CV - Output - shows value over 511 
// L/R Output - shows value over 127
// Center shows ??
// Pot left selects left pause (duty)
// Pot right selects right pause (duty)

int left_potval = 0;
int right_potval = 0;
int left_old_potval = 0;
int right_old_potval = 0;

int LEDColPin[3]; // Left Right Center 
int LEDRowPin[4]; // bottom...top
boolean LEDData[3][4]; // Left Center Right
boolean left_sel, right_sel = false;

unsigned long lastupdate = 0;
  
/* =====================================================
==============INIT DATA STRUCTURES======================
======================================================*/  
void setupDataStruct(){
   for (int i=0; i <= 2; i++){
     for (int j=0; j <= 3; j++){
      LEDData[i][j]=false;
     }
   }
}
/* =====================================================
==============SETUP=====================================
======================================================*/  
void setup()
{ 
  Serial.begin(115200);
  Serial.println();
  Serial.println("");
  Serial.println(F(__FILE__));
  Serial.print(F("Build date: "));
  Serial.println(F(__DATE__));
  delay(50); 
  
  setupDataStruct();
  
// Switch
  pinMode(leftsel, INPUT_PULLUP); 
  pinMode(rightsel, INPUT_PULLUP); 

// POTs
//  pinMode(topleft, INPUT); 
//  pinMode(topright, INPUT); 
  
/* ===========LED Setup=================================*/
  LEDRowPin[0] = row0;
  LEDRowPin[1] = row1;
  LEDRowPin[2] = row2;
  LEDRowPin[3] = row3;

  LEDColPin[0] = col0;
  LEDColPin[1] = col1;
  LEDColPin[2] = col2;
   for (int i=0; i <= 3; i++){
       pinMode(LEDRowPin[i], OUTPUT);
       digitalWrite(LEDRowPin[i], HIGH);
   }
   for (int i=0; i <= 2; i++){
       pinMode(LEDColPin[i], OUTPUT);
       digitalWrite(LEDColPin[i], HIGH);
   }

  updateLED();

// Input

// CV

// PWM Output
  pinMode(leftout, OUTPUT);
  pinMode(rightout, OUTPUT);
}

/* =====================================================
==============MAIN LOOP=================================
======================================================*/  
void loop() { 
  checkpot();
  checkswitch();

  sampleinputs();
  
  updateLED();                     //LED on for active state    
  clearLED();                      //LED off (dim light)

//  updatewave();
  if (millis() > (lastupdate +1000)) {
    Serial.println("");

    Serial.print("state - ");
    Serial.println(sw_state);
    Serial.println("");

    Serial.print("left_potval: ");
    Serial.print(left_potval);
    Serial.print(" - left: ");
    Serial.println(analogRead(topleft));
    
    Serial.print("right_potval: ");
    Serial.print(right_potval);
    Serial.print(" - right: ");
    Serial.println(analogRead(topright));

    Serial.print("left_in: ");
    Serial.println(left_in);
    Serial.print("right_in: ");
    Serial.println(right_in);

    Serial.print("left_cv: ");
    Serial.println(left_cv);
    Serial.print("right_cv: ");
    Serial.println(right_cv);
    
    lastupdate = millis();
  }
}

/* =====================================================
==============Check pot ================================
======================================================*/ 
void checkpot(){
//  int left_potval_local = analogRead(topleft);
//  int right_potval_local = analogRead(topright);
//  if (abs(left_potval - left_potval_local) > 2) left_potval = left_potval_local;
//  if (abs(right_potval - right_potval_local) > 2) right_potval = right_potval_local;
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

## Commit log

2019-05-18 Add Delay Line effect
    Add delay line
    Probable addition:
    Encoder or Pot to decide
    -delay time
    -tap's
    -digital feedback
    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
2019-05-18 Sch resumed from ADSR Atmega32
    [ATMega32A.sch, KicadJE_uP_DAC.kicad_pcb, KicadJE_uP_DAC.sch]
2019-05-19 Hierarchical ATMega32 pins
    [ATMega32A.sch, KicadJE_uP_DAC.sch]
2019-05-19 Ardiono lib initiated
    [_saved_KicadJE_uP_DAC.sch]
2019-05-19 2x Sallen Key LP out from DAC
    [ATMega32A.sch, KicadJE_uP_DAC.sch, _saved_KicadJE_uP_DAC.sch]
2019-05-19 CV and Input protection
    [KicadJE_uP_DAC.sch]
2019-05-19 LED Matrix 3x4
    [KicadJE_uP_DAC.sch]
2019-05-20 Dual uP hierarchy
    [ATMega32A.sch, KicadJE_ATMega32A_DAC.sch, KicadJE_STM32F0.sch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]
2019-05-20 USB - Boot sel - Serial - STM32
    [KicadJE_STM32F0.sch, STM32F103C8.sch, _saved_STM32F103C8.sch]
2019-05-20 STM32 DAC and Analog input
    [KicadJE_STM32F0.sch, STM32F103C8.sch]
2019-05-20 POT GND
    [KicadJE_STM32F0.sch]
2019-05-21 STM32 Pin names for serial and USB
    [KicadJE_STM32F0.sch, STM32F103C8.sch]
2019-05-21 Multiple updates - Initial PCB
    Footprint updates
    LED updates
    [KicadJE_uP_DAC.kicad_pcb]
2019-05-21 Intersheet cleanup
    Footprints and cleanup naming on global labels between sheets
    [ATMega32A.sch, KicadJE_ATMega32A_DAC.sch, KicadJE_STM32F0.sch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]
2019-05-21 LED Matrix ATMega32 rename
    [KicadJE_ATMega32A_DAC.sch, KicadJE_STM32F0.sch, STM32F103C8.sch]
2019-05-21 Sch cleanup and sorting of components in ATMega
    [KicadJE_ATMega32A_DAC.sch, KicadJE_uP_DAC.kicad_pcb]
2019-05-22 LED and Xtal
    [ATMega32A.sch, KicadJE_uP_DAC.kicad_pcb]
2019-05-22 ATMega 32 placed again - decoupling added
    [ATMega32A.sch, KicadJE_uP_DAC.kicad_pcb]
2019-05-22 +5V ATMega
    [KicadJE_uP_DAC.kicad_pcb]
2019-05-22 12V PWR
    [KicadJE_ATMega32A_DAC.sch, KicadJE_uP_DAC.kicad_pcb]
2019-05-23 STM32 Initiated layout
    [KicadJE_ATMega32A_DAC.sch, KicadJE_STM32F0.sch, STM32F103C8.sch]
2019-05-23 Primary components
    [KicadJE_uP_DAC.kicad_pcb]
2019-05-23 Power routed
    [KicadJE_uP_DAC.kicad_pcb]
2019-05-23 Connectors arount STM32
    [KicadJE_uP_DAC.kicad_pcb, _saved_KicadJE_STM32F0.sch]
2019-05-25 serial to DAC - STM32
    [KicadJE_uP_DAC.kicad_pcb]
2019-05-25 Changed Op Amp A and B
    [KicadJE_STM32F0.sch, KicadJE_uP_DAC.kicad_pcb, _saved_KicadJE_STM32F0.sch]
2019-05-25 Output filter routing STM32
    [KicadJE_uP_DAC.kicad_pcb]
2019-05-25 MCP to GNDA and 3.3VA
    [KicadJE_STM32F0.sch, KicadJE_uP_DAC.kicad_pcb]
2019-05-25 Missing Column Driver for column 2 - STM32
    [KicadJE_STM32F0.sch]
2019-05-25 I'll probably have to skip the LED array
    [KicadJE_uP_DAC.kicad_pcb]
2019-05-25 tweaking vias and routing around STM32
    [KicadJE_STM32F0.sch, KicadJE_uP_DAC.kicad_pcb]
2019-05-25 Diode protection - STM32
    [KicadJE_STM32F0.sch, KicadJE_uP_DAC.kicad_pcb]
2019-05-25 STM32 routed without LED's
    [KicadJE_uP_DAC.kicad_pcb]
2019-05-26 Diode etc
    [KicadJE_STM32F0.sch, KicadJE_uP_DAC.kicad_pcb]
2019-05-26 ERC Performed
    [ATMega32A.sch, KicadJE_ATMega32A_DAC.sch, KicadJE_STM32F0.sch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]
2019-05-26 Before ERC Netlist
    [KicadJE_uP_DAC.kicad_pcb]
2019-05-26 Silk update - DDS1 and DDS2 routed
    [KicadJE_uP_DAC.kicad_pcb]
2019-05-26 TH 555 Sheet initiated
    [ATMega32A.sch, KicadJE_ATMega32A_DAC.sch, KicadJE_STM32F0.sch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]
2019-05-27 555 Core VCO Schematic
    [ATMega32A.sch, KicadJE_ATMega32A_DAC.sch, KicadJE_STM32F0.sch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]
2019-05-27 Sch for 555 VCO - Core - Sync - Tri - Ramp done
    [TH_555_VCO1.sch]
2019-05-29 555 Tri Ramp Pulse
    [TH_555_VCO1.sch]
2019-05-29 before sine
    [_saved_TH_555_VCO1.sch]
2019-05-29 Before Sine PCB on 555
    [TH_555_VCO1.sch]
2019-05-30 16p -> 10p on 555 VCO
    [TH_555_VCO1.sch]
2019-05-30 555 PCB
    [KicadJE_uP_DAC.kicad_pcb, TH_555_VCO1.sch]
2019-05-30 Placing outputs and Pots 555
    [KicadJE_uP_DAC.kicad_pcb, TH_555_VCO1.sch]
2019-05-30 555 Pwr to U603
    [KicadJE_uP_DAC.kicad_pcb, TH_555_VCO1.sch]
2019-05-30 555 Power routed
    [KicadJE_uP_DAC.kicad_pcb]
2019-05-30 Labels mixup
    [KicadJE_uP_DAC.kicad_pcb, TH_555_VCO1.sch]
2019-05-30 555 flip
    [KicadJE_uP_DAC.kicad_pcb]
2019-05-30 Most components placed 555
    [KicadJE_uP_DAC.kicad_pcb]
2019-05-30 555 Routed
    [KicadJE_uP_DAC.kicad_pcb]
2019-05-30 label sch + png
    [TH_555_VCO1.sch]
2019-05-30 555 sch boxes
    [TH_555_VCO1.sch]
2019-05-31 ERC Done
    [KicadJE_uP_DAC.kicad_pcb]
2019-05-31 Gerber Rev A done
    [KicadJE_uP_DAC-B_Cu.gbr, KicadJE_uP_DAC-B_Mask.gbr, KicadJE_uP_DAC-B_Paste.gbr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]
2019-10-15 RevB initiated
    [ATMega32A.sch, KicadJE_ATMega32A_DAC.sch, KicadJE_STM32F0.sch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]
2019-10-15 Doepfer power conn reversed :o
    [TH_555_VCO1.sch]
2020-04-14 Update Initial_UI.ino
    Print statements - programming via USBasp and monitoring via serial
2021-05-13 Kicad 5.1
    [ATMega32A.sch, KicadJE_ATMega32A_DAC.sch, KicadJE_STM32F0.sch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]
2021-05-13 STM32 sch
